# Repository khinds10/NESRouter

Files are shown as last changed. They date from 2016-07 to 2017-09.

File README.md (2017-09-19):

# NESRouter
## Using an Old Nintendo Entertainment system case, produce a highly functional home router using a RaspberryPI 3

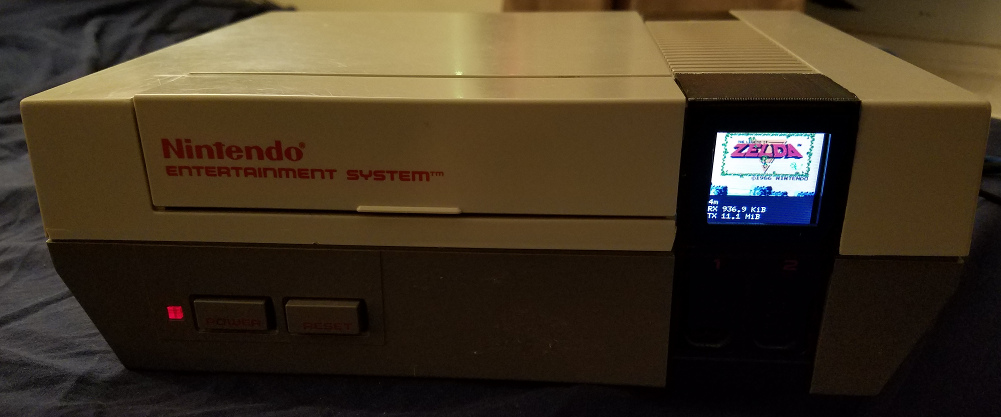
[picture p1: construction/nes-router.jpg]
NES Router w/Screen


#### 1) Flashing RaspberriPi Hard Disk / Install Required Software (Using Ubuntu Linux)

Download "RASPBIAN JESSIE LITE"
https://www.raspberrypi.org/downloads/raspbian/

**Create your new hard disk for DashboardPI**
>Insert the microSD to your computer via USB adapter and create the disk image using the `dd` command
>
> Locate your inserted microSD card via the `df -h` command, unmount it and create the disk image with the disk copy `dd` command
> 
> $ `df -h`
> */dev/sdb1       7.4G   32K  7.4G   1% /media/XXX/1234-5678*
> 
> $ `umount /dev/sdb1`
> 
> **Caution: be sure the command is completely accurate, you can damage other disks with this command**
> 
> *if=location of RASPBIAN JESSIE LITE image file*
> *of=location of your microSD card*
> 
> $ `sudo dd bs=4M if=/path/to/raspbian-jessie-lite.img of=/dev/sdb`
> *(note: in this case, it's /dev/sdb, /dev/sdb1 was an existing factory partition on the microSD)*

**Setting up your RaspberriPi**

*Insert your new microSD card to the raspberrypi and power it on with a monitor connected to the HDMI port*

Login
> user: **pi**
> pass: **raspberry**

Change your account password for security
>`sudo passwd pi`

Enable RaspberriPi Advanced Options
>`sudo raspi-config`

Choose:
`1 Expand File System`

`9 Advanced Options`
>`A2 Hostname`
>*change it to "NESRouter"*
>
>`A4 SSH`
>*Enable SSH Server*
>
>`A7 I2C`
>*Enable i2c interface*

**Enable the English/US Keyboard**

>`sudo nano /etc/default/keyboard`

> Change the following line:
>`XKBLAYOUT="us"`

**Setup the simple directory `l` command [optional]**

>`vi ~/.bashrc`
>
>*add the following line:*
>
>`alias l='ls -lh'`
>
>`source ~/.bashrc`

**Fix VIM default syntax highlighting [optional]**

>`sudo vi  /etc/vim/vimrc`
>
>uncomment the following line:
>
>_syntax on_

Reboot your PI to get the latest changes

`reboot`

### 2) Supplies needed

Old Nintendo Case from a broken NES (remove all the old contents inside the case, leaving only the outside frame, the power / reset buttons and the controller connections)

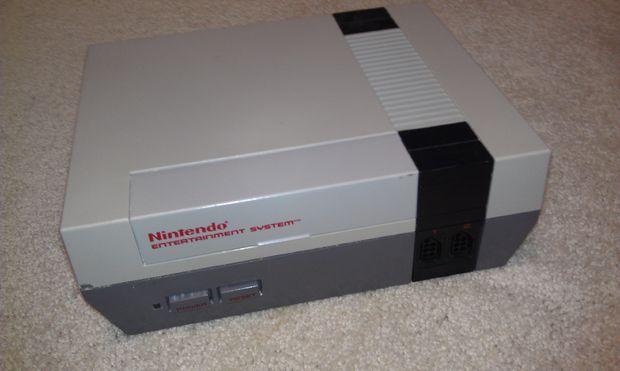
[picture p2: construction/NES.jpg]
Nintendo Case


Raspberry Pi 3 Model B

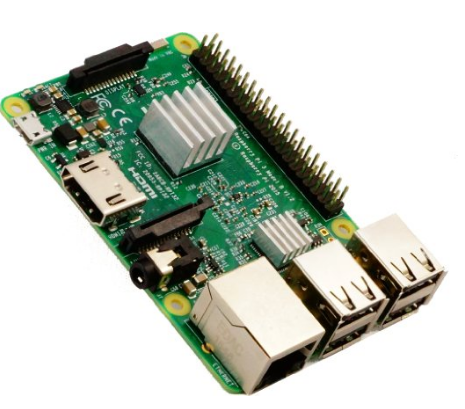
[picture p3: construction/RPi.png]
Raspberry PI 3


1.44" Serial:UART/I2C/SPI TFT LCD 128x128 Display Module

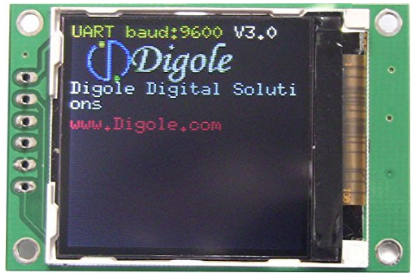
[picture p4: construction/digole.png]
Digole 1.44in display


5V 0.1A Mini Fan Raspberry Pi

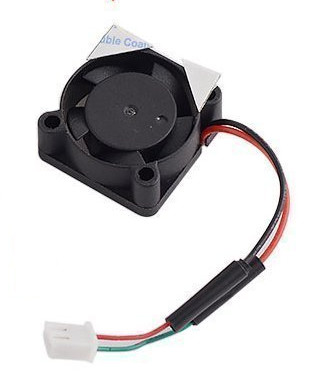
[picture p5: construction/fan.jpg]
Mini Fan


Ugreen USB 2.0 to 10/100 Fast Ethernet Lan Wired Network Adapter

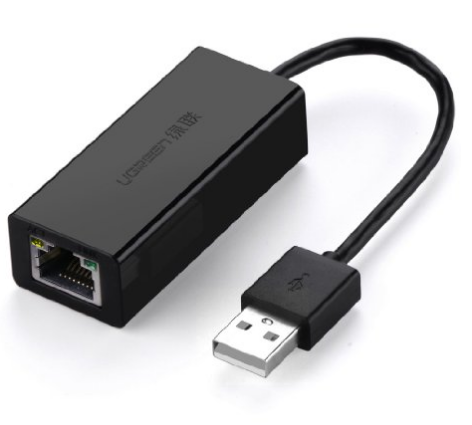
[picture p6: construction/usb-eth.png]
Ethernet USB


**Update local timezone settings**

`sudo dpkg-reconfigure tzdata`

`select your timezone using the interface`

### 3) Creating the WiFi Access Point
**Please note, before this becomes a router we're plugging in the RaspberryPi to an existing network via its ethernet port to install the following packages**

`sudo apt-get update && sudo apt-get -y upgrade`

`sudo apt-get install dnsmasq hostapd vim`

`sudo apt-get install vim git python-smbus i2c-tools python-imaging python-smbus build-essential python-dev rpi.gpio python3 python3-pip libi2c-dev`

`sudo vi /etc/dhcpcd.conf`

Add the following line:

    denyinterfaces wlan0

`sudo vi /etc/network/interfaces`

Edit the wlan0 section so that it looks like this:

    auto lo
    iface lo inet loopback

    iface eth0 inet manual

    auto wlan0
    iface wlan0 inet static
        address 10.0.10.1
        netmask 255.255.255.0
        network 10.0.10.0
        broadcast 10.0.10.255

    auto eth1
    iface eth1 inet static
        address 10.0.20.1
        netmask 255.255.255.0
        network 10.0.20.0
        broadcast 10.0.20.255

Reload DHCP Server and bounce the configuration for eth0 and wlan0 connections

`sudo service dhcpcd restart`

`sudo ifdown eth0; sudo ifup wlan0`

#### Configure HOSTAPD (Change ssid and wpa_passphrase to the values of your own choosing)

`sudo vi /etc/hostapd/hostapd.conf`

    # This is the name of the WiFi interface we configured above
    interface=wlan0

    # Use the nl80211 driver with the brcmfmac driver
    driver=nl80211

    # This is the name of the network
    ssid=NintendoWiFi

    # Use the 2.4GHz band
    hw_mode=g

    # Use channel 6
    channel=6

    # Enable 802.11n
    ieee80211n=1

    # Enable WMM
    wmm_enabled=1

    # Enable 40MHz channels with 20ns guard interval
    ht_capab=[HT40][SHORT-GI-20][DSSS_CCK-40]

    # Accept all MAC addresses
    macaddr_acl=0

    # Use WPA authentication
    auth_algs=1

    # Require clients to know the network name
    ignore_broadcast_ssid=0

    # Use WPA2
    wpa=2

    # Use a pre-shared key
    wpa_key_mgmt=WPA-PSK

    # The network passphrase
    wpa_passphrase=password

    # Use AES, instead of TKIP
    rsn_pairwise=CCMP

We can check if it's working at this stage by running (but doesn't have full internet connectivity yet):

`sudo /usr/sbin/hostapd /etc/hostapd/hostapd.conf`

`sudo vi /etc/default/hostapd`

Find the line 

    #DAEMON_CONF="" 
    
and replace it with 

    DAEMON_CONF="/etc/hostapd/hostapd.conf"

Configure DNSMASQ

`sudo mv /etc/dnsmasq.conf /etc/dnsmasq.conf.orig`

`sudo vi /etc/dnsmasq.conf`

    bind-interfaces           # Bind to the interface to make sure we aren't sending things elsewhere
    server=8.8.8.8            # Forward DNS requests to Google DNS
    domain-needed             # Don't forward short names
    bogus-priv                # Never forward addresses in the non-routed address spaces.

    # Assign IP addresses w/infinite lease time (for device usage stats)
    dhcp-range=wlan0,10.0.10.100,10.0.10.200,255.255.255.0,10.0.10.255,infinite
    dhcp-range=eth1,10.0.20.100,10.0.20.200,255.255.255.0,10.0.20.255,infinite 

SET UP IPV4 FORWARDING

`sudo vi /etc/sysctl.conf`

[uncomment]
net.ipv4.ip_forward=1

Activate it immediately with
`sudo sh -c "echo 1 > /proc/sys/net/ipv4/ip_forward"`

`sudo iptables -t nat -A POSTROUTING -o eth0 -j MASQUERADE`

`sudo iptables -A FORWARD -i eth0 -o eth1 -m state --state RELATED,ESTABLISHED -j ACCEPT`

`sudo iptables -A FORWARD -i eth1 -o eth0 -j ACCEPT`

`sudo iptables -A FORWARD -i eth0 -o wlan0 -m state --state RELATED,ESTABLISHED -j ACCEPT`

`sudo iptables -A FORWARD -i wlan0 -o eth0 -j ACCEPT`

Save iptables settings for next reboot

`sudo sh -c "iptables-save > /etc/iptables.ipv4.nat"`

Create ipv4 rules file (with new contents)

`sudo vi /lib/dhcpcd/dhcpcd-hooks/70-ipv4-nat`

    iptables-restore < /etc/iptables.ipv4.nat

Restart Services

`sudo service hostapd start`
`sudo service dnsmasq start`

`sudo reboot`

#### Assigning Static IPs [Optional]
**If you would like hosts on your network to have static ips please use the following**

Aquire the hosts currently connected via DHCP
`vi /var/lib/misc/dnsmasq.leases`

Add the MAC Address (from output above) and the IP address you would like to assign them to
`sudo vi /etc/dnsmasq.conf`

    # main desktop
    dhcp-host=12:34:56:78:9a:bc,10.0.20.20

**Note: This will assign the network interface with the MAC Address: 12:34:56:78:9a:bc to IP address 10.0.20.20. The IP address listed does NOT have to be in the DHCP range given, just on the same subnet.  My main desktop above is on subnet eth1:10.0.20.0, so I gave it IP Address of 10.0.20.20.**

#### Adding UFW Firewall

`sudo apt-get install ufw`

Allow port 22 for public use (for remote network access)

`sudo ufw allow 22`

Allow all ports on my local network

`sudo ufw allow from 10.0.10.0/24`
`sudo ufw allow from 10.0.20.0/24`

Allow web ports to everyone

`sudo ufw allow 80`

Allow secure web ports to everyone

`sudo ufw allow 443`

Enable UFW and check the status

`sudo ufw --force enable`

`sudo ufw status`

Fix BUG with UFW not starting on startup

`sudo su`
`crontab -e`

Add the following line:
`@reboot /bin/sleep 60; ufw --force enable`

## Construction

### Install inside the NES

1) Using a 3D printer print the Digole Display frame "NESPanel" in the `/construction/display-frame/` folder. [if you don't have a 3D printer you could delicately cut a square hole for the Digole Display with a Dremel tool]

2) Cut the following holes open in the back and side of the case to allow for the small fan to be fastened on the side and the
power/ethernet and USB ethernet cables to get in through the back.

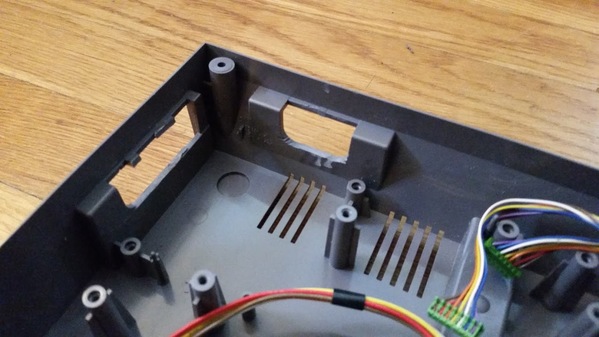
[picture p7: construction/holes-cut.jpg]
Holes Cut


3) Unscrew the top right black panel from the NES and cleanly cut a large enough square hole to mount your digole display. Hot Glue the display in place with the "NESPanel" 3D printed frame over the top of it.

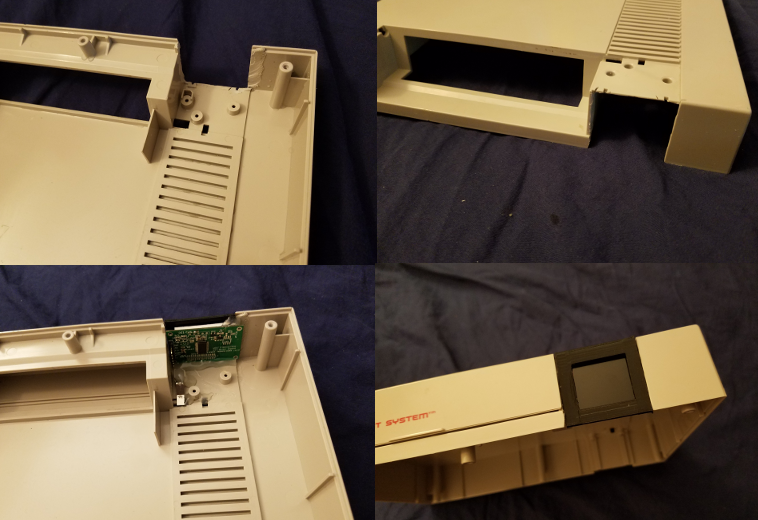
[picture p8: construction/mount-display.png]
Mount Digole Display


4) Mount the RaspberryPi in the middle of the bottom of the empty NES case, fasten by glue or a small screw through the bottom.
Using a 270 ohm resister, connect the "power on LED" of the NES to the 5V and GND pins in the Raspberry Pi (short LED lead is the ground).
Connect the small fan to the 5V and GND pins as well to have it run when the unit starts up, glue the fan against the hole in the side for it.

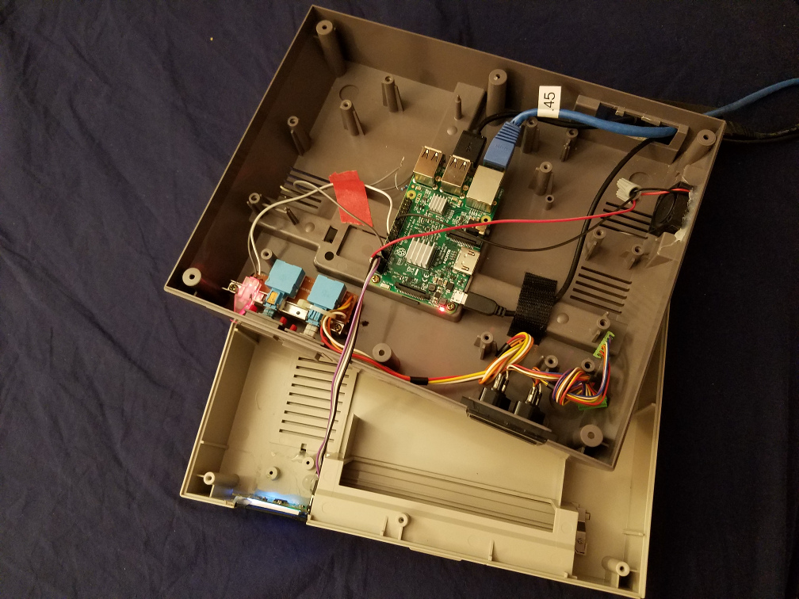
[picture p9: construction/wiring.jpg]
Wiring

 
### Connecting the Digole Display

Connect the following pins to the pins on the RaspberryPi
    
    VCC is connected to 3v
    GND is ground
    DATA is SDA
    CLOCK is SCL

Now you should see the device in your i2cdetect command

`i2cdetect -y 1`
*it should show up in the grid of text as 27*

### Install network monitoring tools & DB Logging

`sudo apt-get install ifstat memcached python-memcache postgresql postgresql-contrib python-psycopg2`

`sudo vi /etc/postgresql/9.4/main/pg_hba.conf`
>Add the following line to the end of the file:
>local all pi password

`sudo -i -u postgres`

`psql`

`create role pi password 'password here';`

`alter role pi login;`

`alter role pi superuser;`

`\du`

>(you should see your PI user with the permissions granted)

`create database network_stats;`

`\q`

`exit`

`psql -d network_stats`

Run the following queries:
        
>CREATE TABLE traffic\_per\_minute (
>    id serial,
>    time timestamp without time zone NOT NULL,
>    eth0\_down real,
>    eth0\_up real,
>    eth1\_down real,
>    eth1\_up real,
>    wan0\_down real,
>    wan0\_up real
>);
> 
>CREATE UNIQUE INDEX time\_idx ON traffic\_per\_minute (time);

Copy the "logging" folder of code from this project to the home directory of your RPi

`crontab -e`

Add this line

`@reboot /bin/sleep 60; nohup python /home/pi/logging/networkUsage.py >/dev/null 2>&1`

### Install the traffic summary report (runs every 5 minutes by cronjob)

`crontab -e`

add the following line

> */5 * * * * python /home/pi/logging/trafficSummary.py

### Install the dashboard screen

Copy the "display" folder of code from this project to the home directory of your RPi

Run it as follows

>$ `python /home/pi/display/NESRouter.py`

Setup the display script to run at startup

`crontab -e`

Add this line

`@reboot nohup python /home/pi/display/NESRouter.py >/dev/null 2>&1`

Verify the display starts working on reboot

`sudo reboot`

### Install the local usage/statistics website [http://10.0.10.1]

`sudo apt-get update && sudo apt-get upgrade -y`

`sudo apt-get install apache2`

`sudo service apache2 restart`

Remove default pages

`cd /var/www`

`sudo rm -rf html`
   
Copy 'webportal' folder from this project to your home folder on your RPi and create the symlink for apache to use
  
`cd /var/www`

`sudo ln -s /home/pi/webportal html`

`cd /var/www/html`

`chmod +x *.py`

`sudo a2enmod cgi`

`sudo vi /etc/apache2/sites-enabled/000-default.conf`

Enable Python CGI Scripting 

**Add inside the <virtual\> tag**

> <Directory /var/www/html\>
>   Options +ExecCGI
>   AddHandler cgi-script .py
> </Directory\>

`sudo service apache2 restart`
 
You can now visit the local HTTP site [http://10.0.10.1]

### Setup advanced network monitoring (via IPFM)

`sudo apt-get update`

`sudo apt-get install ipfm`

`sudo mv /etc/ipfm.conf /etc/ipfm.conf-bak`

`sudo vi /etc/ipfm.conf`

Create with the following contents:

> \# Global variables
> 
> \# IPFM can monitor only one device.
> DEVICE eth0
> 
> \# GLOBAL LOGGING CONFIGURATION
> LOG
> 
> FILENAME "/var/log/ipfm/%Y_%d_%m/%H_%M"
> 
> \# log every minute
> DUMP EVERY 1 minute
> 
> \# clear statistics each day
> CLEAR EVERY 24 hour
> SORT IN
> RESOLVE

`sudo service ipfm start`

## OPTIONAL: Creating your own Nintendo images to render on the display

Upload your own 128x128 file to the following URL:

http://www.digole.com/tools/PicturetoC_Hex_converter.php 

Choose your image file to upload, add what size you want it to be on the screen (Width/Height)

Select "256 Color for Color OLED/LCD(1 byte/pixel)" in the "Used for" dropdown

Obtain the hex output.

Add the hex output to a display/build/ header (.h) file, use the other ones as guides for syntax.

Include the new file in the digole.c file 
`#include "myimage.h`

Include a new command line hook to your image file in the.
_Note: the command below is saying draw your image at position 10 pixels over 10  pixels down. You can change it to different X,Y coordinates, you can also change the values 128,128 to whatever size your new image actually is._

`} else if (strcmp(digoleCommand, "myimage") == 0) {`
    `drawBitmap256(10, 10, 128, 128, &myimageVariableHere,0);  // myimageVariableHere is defined in your (.h) file`
`}`

Now rebuild (ignore the errors) below to have your new image render with the following command.
>$ `./digole myimage`

**Re-Building [Included] Digole Display Driver for your optional changes**

>$ `cd display/build`

>$ `gcc digole.c`

>$ `mv a.out ../../digole`

>$ `chmod +x ../../digole`

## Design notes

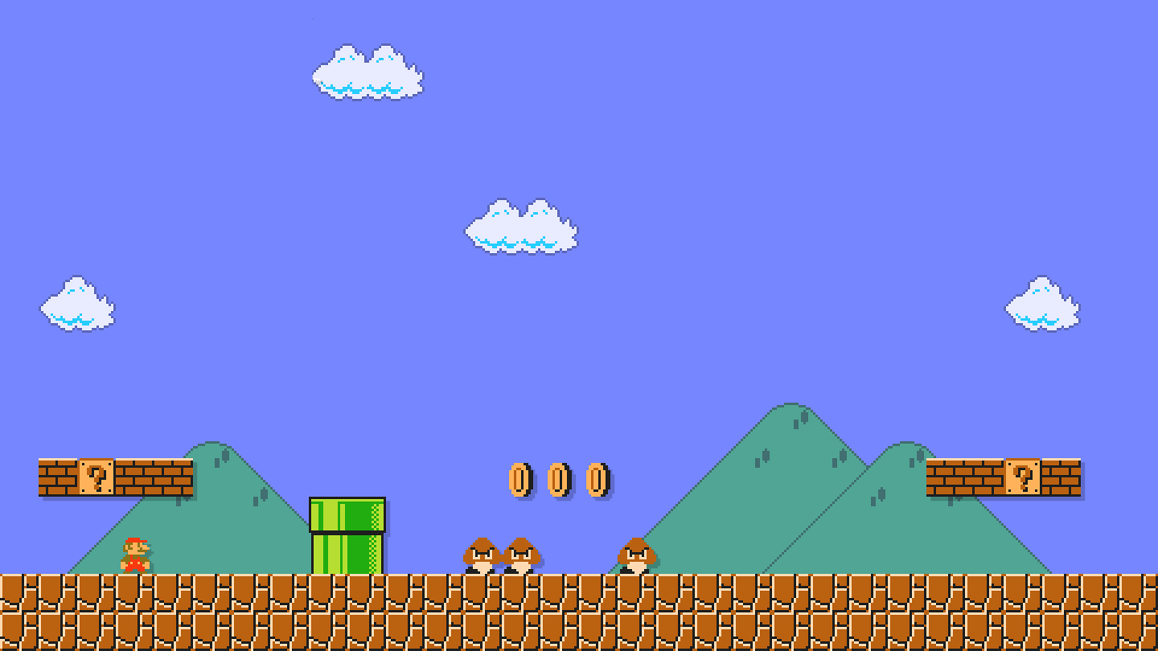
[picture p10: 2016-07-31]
webportal/img/wallpaper.png

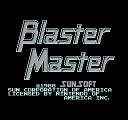
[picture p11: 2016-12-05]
display/compile/images/BlasterMaster.png

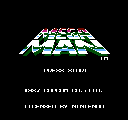
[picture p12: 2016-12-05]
display/compile/images/MegaMan.png

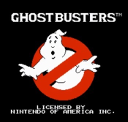
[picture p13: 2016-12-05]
display/compile/images/GhostBusters.png

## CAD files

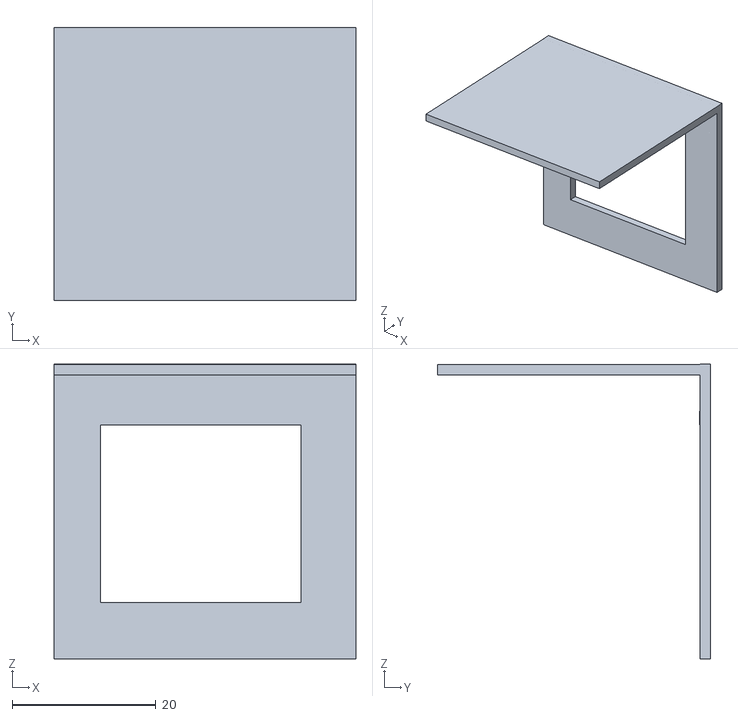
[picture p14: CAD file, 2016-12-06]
construction/display-frame/nesPanel.stl
42.0 x 38.0 x 41.0

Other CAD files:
construction/display-frame/nesPanel.blend

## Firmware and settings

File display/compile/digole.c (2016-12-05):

/////////////////////////////////
// Digole Digital
/////////////////////////////////
#include <arpa/inet.h>
#include <dirent.h>
#include <errno.h>
#include <net/if.h>
#include <netinet/in.h>
#include <netinet/in.h>
#include <pthread.h>
#include <stdint.h>
#include <stdio.h>
#include <stdlib.h>
#include <string.h>
#include <stropts.h>
#include <sys/ioctl.h>
#include <sys/socket.h>
#include <sys/types.h>
#include <sys/time.h>
#include <time.h>
#include <unistd.h>
#include <inttypes.h>
#include <linux/i2c-dev.h>
#include <fcntl.h>
#include <sys/ioctl.h>
#include <sys/stat.h>

// include all the NES Title Screen Images
#include "BlasterMaster.h""
#include "Castlevania.h""
#include "ChipDale.h""
#include "Contra.h""
#include "DuckTales.h""
#include "Galaga.h""
#include "GhostBusters.h""
#include "Gradius.h""
#include "KidIcarus.h""
#include "MarbleMadness.h""
#include "MegaMan.h""
#include "MetalGear.h""
#include "Metroid.h""
#include "PunchOut.h""
#include "SuperMario2.h""
#include "SuperMario3.h""
#include "TMNT2.h""
#include "TopGun.h""
#include "Turtles.h""
#include "Zelda.h""

#define _TEXT_ 0
#define _GRAPH_ 1
#define _rs 0
#define _rst 2
#define LCDWIDTH 128
#define LCDHEIGHT 64

// an abs() :)
#define abs(a) (((a) < 0) ? -(a) : (a))

// bit set
#define _BV(bit) (0x1 << (bit))
#define swap(a, b) { uint8_t t = a; a = b; b = t; }

int fd,fd2;
const unsigned char fonts[] = {6, 10, 18, 51, 120, 123};

// name of the port we will be using, Rasberry Pi model B (i2c-1)
char *fileName = "/dev/i2c-1";

// address of I2C device Digole
int  address = 0x27;

void delay (unsigned int howLong){
  struct timespec sleeper, dummy ;
  sleeper.tv_sec  = (time_t)(howLong / 1000) ;
  sleeper.tv_nsec = (long)(howLong % 1000) * 1000000 ;
  nanosleep (&sleeper, &dummy) ;
}
 int writebyte (uint8_t command) {
	    if( i2c_smbus_write_byte( fd, command ) < 0 ) {
            printf(" Error writing to i2c slave ");
			return -1;
        }
		return 0;
 }
 int writecmd(char *command) {
		char tmp[1000];
		int i;
		sprintf(tmp,"%s",command);
        printf(" Digole CMD: %s ",command);
		for (i=0;i<strlen(tmp);i++) {
			printf("%c",tmp[i]);
		    if ((writebyte(tmp[i]))==-1) {
				printf(" Error writing to i2c slave ");
				return -1;
			}
		}
		return 0;
 }
void setRot90(void) {
    writecmd("SD1");
}
void setRot180(void) {
    writecmd("SD2");
}
void setRot270(void) {
    writecmd("SD3");
}
void undoRotation(void) {
    writecmd("SD0");
}
void setRotation(uint8_t d) {
    writecmd("SD");
    writebyte(d);
}
void setContrast(uint8_t c) {
    writecmd("CT");
    writebyte(c);
}
int print(char *command) {
    char tmp[1000];
    writecmd("TT");
    writecmd(command);
    writebyte(0);
    return 0;
}
void displayStartScreen(uint8_t c) {
    writecmd("DSS");
    writebyte(c);
}
void drawBox(uint8_t x, uint8_t y, uint8_t w, uint8_t h) {
    writecmd("FR");
    writebyte(x);
    writebyte(y);
    writebyte(x + w);
    writebyte(y + h);
}
void drawFrame(uint8_t x, uint8_t y, uint8_t w, uint8_t h) {
    writecmd("DR");
    writebyte(x);
    writebyte(y);
    writebyte(x + w);
    writebyte(y + h);
}
void setColor(uint8_t color) {
    writecmd("SC");
    writebyte(color);
}
void drawBoxfill(uint8_t x, uint8_t y, uint8_t w, uint8_t h) {
	setColor(0);
	drawBox(x, y, w,h);
	setColor(1);
	drawFrame(x, y, w,h);
}
void clearobd() {
	setColor(0);
	drawBox(0, 0, 128,57);
	setColor(1);
}
void drawCircle(uint8_t x, uint8_t y, uint8_t r, uint8_t f) {
    writecmd("CC");
    writebyte(x);
    writebyte(y);
    writebyte(r);
    writebyte(f);
}
void drawDisc(uint8_t x, uint8_t y, uint8_t r) {
    drawCircle(x, y, r, 1);
}
void drawPixel(uint8_t x, uint8_t y, uint8_t color) {
    writecmd("DP");
    writebyte(x);
    writebyte(y);
    writebyte(color);
}
void drawLine(uint8_t x, uint8_t y, uint8_t x1, uint8_t y1) {
    writecmd("LN");
    writebyte(x);
    writebyte(y);
    writebyte(x1);
    writebyte(y1);
}
void drawLineTo(uint8_t x, uint8_t y) {
    writecmd("LT");
    writebyte(x);
    writebyte(y);
}
void drawHLine(uint8_t x, uint8_t y, uint8_t w) {
    drawLine(x, y, x + w, y);
}
void drawVLine(uint8_t x, uint8_t y, uint8_t h) {
    drawLine(x, y, x, y + h);
}
void nextTextLine(void) {
    writebyte((uint8_t) 0);
    writecmd("TRT");
}
void setFont(uint8_t font) {
    writecmd("SF");
    writebyte(font);
}
void directCommand(uint8_t d) {
    writecmd("MCD");
    writebyte(d);
}
void directData(uint8_t d) {
    writecmd("MDT");
    writebyte(d);
}
void moveArea(uint8_t x0, uint8_t y0, uint8_t x1, uint8_t y1, char xoffset, char yoffset) {
    writecmd("MA");
    writebyte(x0);
    writebyte(y0);
    writebyte(x1);
    writebyte(y1);
    writebyte(xoffset);
    writebyte(yoffset);
}
void uploadStartScreen(int lon,  uint8_t *data,int xdelay) {
     int j,y;
     uint8_t c;
    writecmd("SSS");
    writebyte((uint8_t) (lon % 256));
    writebyte((uint8_t) (lon / 256));
    for (j = 0; j < lon;j++) {
        delay(xdelay);
        c=*(data+j);
        writebyte(c);
		printf(" 0x%.2X ",c);
		if ((j%16)==0) printf(" ");
    }
}
void uploadUserFont(int lon, uint8_t *data, uint8_t sect) {
     uint8_t c;
	 int j;
    writecmd("SUF");
    writebyte(sect);
    writebyte((uint8_t) (lon % 256));
    writebyte((uint8_t) (lon / 256));
    for ( j = 0; j < lon; j++) {
        if((j%32)==0) delay(10);
        delay(2);
        c=*(data+j);
        writebyte(c);
    }
}
void clearScreen(void) {
        writebyte('C');
		writebyte('L');
		writebyte(0);
		writebyte('C');
		writebyte('L');
		writebyte(0);
}
//set display mode
void setMode(uint8_t m) {
        writecmd("DM");
        writebyte(m);
}
//set text position back to previous, only one back allowed
void setTextPosBack(void) {
	writecmd("ETB");
}
void setTextPosOffset(char xoffset, char yoffset) {
	writecmd("ETO");
	writebyte(xoffset);
	writebyte(yoffset);
}
void setTextPosAbs(uint8_t x, uint8_t y) {
	writecmd("ETP");
	writebyte(x);
	writebyte(y);
}
void setLinePattern(uint8_t pattern) {
	writecmd("SLP");
	writebyte(pattern);
 }
void setPrintPos(uint8_t x, uint8_t y, uint8_t graph ) {
        if (graph == _TEXT_)
            writecmd("TP");
		else
            writecmd("GP");
         writebyte(x);
         writebyte(y);
}
void disableCursor(void) {
    writecmd("CS0");
}
void enableCursor(void) {
    writecmd("CS1");
}
void drawStr(uint8_t x, uint8_t y, char *s) {
		setTextPosOffset(x,y);
		print(s);
}
/*----------Functions for Graphic LCD/OLED adapters only---------*/
void drawBitmap(uint8_t x, uint8_t y, uint8_t w, uint8_t h, const uint8_t *bitmap) {
    uint8_t i = 0;
	int j;
    if ((w & 7) != 0)
        i = 1;
    writecmd("DIM");
    writebyte(x); //x;
    writebyte(y);
    writebyte(w);
    writebyte(h);
    for ( j = 0; j < h * ((w >> 3) + i); j++) {
        writebyte(*(bitmap + j));
    }
}
void drawBitmap256(uint8_t x, uint8_t y, uint8_t w, uint8_t h, unsigned char *bitmap,uint8_t c ) {
	int j;
    writecmd("EDIM1");
    writebyte(x);
    writebyte(y);
    writebyte(w);
    writebyte(h);    
    for ( j = 0; j < h * w; j++) {
        writebyte(*(bitmap + j));
    }
}
void drawBitmapc(uint8_t x, uint8_t y, uint8_t w, uint8_t h, unsigned char *bitmap,uint8_t c ) {
    uint8_t i = 0;
	int j;
	if (c!=0) c=0xff;
    if ((w & 7) != 0)
        i = 1;
    writecmd("EDIM1");
    writebyte(x);
    writebyte(y);
    writebyte(w);
    writebyte(h);
    for ( j = 0; j < h * ((w >> 3) + i); j++) {
        writebyte((*(bitmap + j))^c);
    }
}
const char *byte_to_binary(int x) {
    static char b[9];
    b[0] = '\0';
    int z;
    for (z = 128; z > 0; z >>= 1){
        strcat(b, ((x & z) == z) ? "1" : "0");
    }
    return b;
}
 int printxy(uint8_t x, uint8_t y, char *command) {
	setPrintPos(x, y,_TEXT_);
	writecmd("TT");
	writecmd(command);
	writebyte(0);
	return 0;
 }
 int printxy_abs(uint8_t x, uint8_t y, char *command) {
	setTextPosAbs(x, y);
	writecmd("TT");
	writecmd(command);
	writebyte(0);
	return 0;
 }
 int printxyf_abs(uint8_t x, uint8_t y,uint8_t font, char *command) {
	setFont(fonts[font]);
	setTextPosAbs(x, y);
	writecmd("TT");
	writecmd(command);
	writebyte(0);
	return 0;
 }
int printxyf(uint8_t x, uint8_t y,uint8_t font, char *command) {
	setFont(fonts[font]);
	setPrintPos(x, y,_TEXT_);
	writecmd("TT");
	writecmd(command);
	writebyte(0);
	return 0;
 }
int printnxyf(uint8_t x, uint8_t y,uint8_t font, int command) {
    char tmp[100];
    sprintf(tmp,"%d",command);
    setFont(fonts[font]);
    setPrintPos(x, y,_TEXT_);
    writecmd("TT");
    writecmd(tmp);
    writebyte(0);
    return 0;
 }
 int printnxyf_abs(uint8_t x, uint8_t y,uint8_t font, int command) {
    char tmp[100];
    sprintf(tmp,"%d",command);
    setFont(fonts[font]);
    setTextPosAbs(x, y);
    writecmd("TT");
    writecmd(tmp);
    writebyte(0);
    return 0;
 }
int LCDInit( uint8_t contrast) {
    // Open port for reading and writing
    if ((fd = open (fileName, O_RDWR)) < 0) {
        printf(" Failed to open i2c port ");
        return -1;
    }
    // Set the port options and set the address of the device
    if (ioctl(fd, I2C_SLAVE, address) < 0) {
        printf(" Unable to get bus access to talk to slave ");
        return -1;
    }
	return (0);
}
void LCDdrawbitmap(uint8_t x, uint8_t y, uint8_t *bitmap, uint8_t w, uint8_t h,uint8_t color,uint8_t *dest) {
uint8_t j,i,jj;
uint8_t o,p,k;
printf(" 000 0b ");
k=0;
for (p=0;p<(w/8);p++)
  for (o=0;o<=7;o++) {
		for ( j=0; j<h; j++) {
			for ( i=0; i<(w/8); i++ ) {
				uint8_t d = *(bitmap + i + (j)*w/8);
				for (jj = 8; jj>0; jj--)	{
					if (((jj-1)==(7-o)) && (i==p)) {
						if (d & _BV(jj-1))
						  printf("1");
						else
						  printf("0");
						k++;
						if (k%8==0)
							printf(",0b");
					 }
				}
			}
		}
		k=0;
		printf(" %.03d 0b ",(p*8)+o);
	}
}

int main (int argc, char* argv[]) {
    int i=0;
	LCDInit(0);
    printf(" %s ", argv[0]);

    // show incoming commands   
    printf(" arg%d=%s ", 1, argv[1]);
    printf(" arg%d=%s ", 2, argv[2]);

    // parse command to char
    char digoleCommand[100];
    sprintf(digoleCommand,"%s",argv[1]);
    
    // based on command issue call to Digole screen
    if (strcmp(digoleCommand, "setRot90") == 0) {
        setRot90();
    } else if (strcmp(digoleCommand, "setRot180") == 0) {
        setRot180();
    } else if (strcmp(digoleCommand, "setRot270") == 0) {
        setRot270();
    } else if (strcmp(digoleCommand, "undoRotation") == 0) {
        undoRotation();
    } else if (strcmp(digoleCommand, "setRotation") == 0) {
        setRotation((uint8_t)atoi(argv[2]));
    } else if (strcmp(digoleCommand, "setContrast") == 0) {
        setContrast((uint8_t)atoi(argv[2]));
    } else if (strcmp(digoleCommand, "displayStartScreen") == 0) {
        displayStartScreen((uint8_t)atoi(argv[2]));
    } else if (strcmp(digoleCommand, "drawBox") == 0) {
        drawBox((uint8_t)atoi(argv[2]), (uint8_t)atoi(argv[3]), (uint8_t)atoi(argv[4]), (uint8_t)atoi(argv[5]));
    } else if (strcmp(digoleCommand, "drawFrame") == 0) {
        drawFrame((uint8_t)atoi(argv[2]), (uint8_t)atoi(argv[3]), (uint8_t)atoi(argv[4]), (uint8_t)atoi(argv[5]));
    } else if (strcmp(digoleCommand, "setColor") == 0) {
        setColor((uint8_t)atoi(argv[2]));
    } else if (strcmp(digoleCommand, "drawBoxfill") == 0) {
        drawBoxfill((uint8_t)atoi(argv[2]), (uint8_t)atoi(argv[3]), (uint8_t)atoi(argv[4]), (uint8_t)atoi(argv[5]));
    } else if (strcmp(digoleCommand, "clearobd") == 0) {
        clearobd();
    } else if (strcmp(digoleCommand, "drawCircle") == 0) {
        drawCircle((uint8_t)atoi(argv[2]), (uint8_t)atoi(argv[3]), (uint8_t)atoi(argv[4]), (uint8_t)atoi(argv[5]));
    } else if (strcmp(digoleCommand, "drawDisc") == 0) {
        drawDisc((uint8_t)atoi(argv[2]), (uint8_t)atoi(argv[3]), (uint8_t)atoi(argv[4]));
    } else if (strcmp(digoleCommand, "drawPixel") == 0) {
        drawPixel((uint8_t)atoi(argv[2]), (uint8_t)atoi(argv[3]), (uint8_t)atoi(argv[4]));
    } else if (strcmp(digoleCommand, "drawLine") == 0) {
        drawLine((uint8_t)atoi(argv[2]), (uint8_t)atoi(argv[3]), (uint8_t)atoi(argv[4]), (uint8_t)atoi(argv[5]));
    } else if (strcmp(digoleCommand, "drawLineTo") == 0) {
        drawLineTo((uint8_t)atoi(argv[2]), (uint8_t)atoi(argv[3]));
    } else if (strcmp(digoleCommand, "drawHLine") == 0) {
        drawHLine((uint8_t)atoi(argv[2]), (uint8_t)atoi(argv[3]), (uint8_t)atoi(argv[4]));
    } else if (strcmp(digoleCommand, "drawVLine") == 0) {
        drawVLine((uint8_t)atoi(argv[2]), (uint8_t)atoi(argv[3]), (uint8_t)atoi(argv[4]));
    } else if (strcmp(digoleCommand, "nextTextLine") == 0) {
        nextTextLine();
    } else if (strcmp(digoleCommand, "setFont") == 0) {
        setFont((uint8_t)atoi(argv[2]));
    } else if (strcmp(digoleCommand, "directCommand") == 0) {
        directCommand((uint8_t)atoi(argv[2]));
    } else if (strcmp(digoleCommand, "directData") == 0) {
        directData((uint8_t)atoi(argv[2]));
    } else if (strcmp(digoleCommand, "moveArea") == 0) {
        moveArea((uint8_t)atoi(argv[2]), (uint8_t)atoi(argv[3]), (uint8_t)atoi(argv[4]), (uint8_t)atoi(argv[5]), (uint8_t)atoi(argv[6]), (uint8_t)atoi(argv[7]));
    } else if (strcmp(digoleCommand, "uploadStartScreen") == 0) {
        // uploadStartScreen(int lon,  uint8_t *data,int xdelay);
    } else if (strcmp(digoleCommand, "uploadUserFont") == 0) {
        // uploadUserFont(int lon, uint8_t *data, uint8_t sect);
    } else if (strcmp(digoleCommand, "clear") == 0) {
        clearScreen();
    } else if (strcmp(digoleCommand, "setMode") == 0) {
        setMode((uint8_t)atoi(argv[2]));
    } else if (strcmp(digoleCommand, "setTextPosBack") == 0) {
        setTextPosBack();
    } else if (strcmp(digoleCommand, "setTextPosOffset") == 0) {
        setTextPosOffset((uint8_t)atoi(argv[2]), (uint8_t)atoi(argv[3]));
    } else if (strcmp(digoleCommand, "setTextPosAbs") == 0) {
        setTextPosAbs((uint8_t)atoi(argv[2]), (uint8_t)atoi(argv[3]));
    } else if (strcmp(digoleCommand, "setLinePattern") == 0) {
        setLinePattern((uint8_t)atoi(argv[2]));
    } else if (strcmp(digoleCommand, "setPrintPos") == 0) {
        setPrintPos((uint8_t)atoi(argv[2]), (uint8_t)atoi(argv[3]), (uint8_t)atoi(argv[4]));
    } else if (strcmp(digoleCommand, "disableCursor") == 0) {
        disableCursor();
    } else if (strcmp(digoleCommand, "enableCursor") == 0) {
        enableCursor();
    } else if (strcmp(digoleCommand, "drawStr") == 0) {
        drawStr((uint8_t)atoi(argv[2]), (uint8_t)atoi(argv[3]), argv[4]);
    } else if (strcmp(digoleCommand, "drawBitmap") == 0) {
        // drawBitmap((uint8_t)atoi(argv[2]), (uint8_t)atoi(argv[3]), (uint8_t)atoi(argv[4]), (uint8_t)atoi(argv[5]), (uint8_t)atoi(argv[2]));
    } else if (strcmp(digoleCommand, "drawBitmap256") == 0) {
        // drawBitmapc((uint8_t)atoi(argv[2]), (uint8_t)atoi(argv[2]), (uint8_t)atoi(argv[2]), (uint8_t)atoi(argv[2]), const uint8_t *bitmap,uint8_t c );
    } else if (strcmp(digoleCommand, "print") == 0) {
        print(argv[2]);
    } else if (strcmp(digoleCommand, "printxy") == 0) {
        printxy((uint8_t)atoi(argv[2]), (uint8_t)atoi(argv[3]), argv[4]);
    } else if (strcmp(digoleCommand, "printxy_abs") == 0) {
        printxy_abs((uint8_t)atoi(argv[2]), (uint8_t)atoi(argv[3]), argv[4]);
    } else if (strcmp(digoleCommand, "printxyf_abs") == 0) {
        printxyf_abs((uint8_t)atoi(argv[2]), (uint8_t)atoi(argv[3]),(uint8_t)atoi(argv[4]), argv[5]) ;
    } else if (strcmp(digoleCommand, "printxyf") == 0) {
        printxyf((uint8_t)atoi(argv[2]), (uint8_t)atoi(argv[3]),(uint8_t)atoi(argv[4]), argv[5]);
    } else if (strcmp(digoleCommand, "printnxyf") == 0) {
        printnxyf((uint8_t)atoi(argv[2]), (uint8_t)atoi(argv[3]),(uint8_t)atoi(argv[4]), (uint8_t)atoi(argv[5]));
    } else if (strcmp(digoleCommand, "printnxyf_abs") == 0) {
        printnxyf_abs((uint8_t)atoi(argv[2]), (uint8_t)atoi(argv[3]),(uint8_t)atoi(argv[4]), (uint8_t)atoi(argv[5]));
    } else if (strcmp(digoleCommand, "LCDdrawbitmap") == 0) {
        //LCDdrawbitmap((uint8_t)atoi(argv[2]), (uint8_t)atoi(argv[3]), (uint8_t)atoi(argv[4]), (uint8_t)atoi(argv[5]), (uint8_t)atoi(argv[6]),(uint8_t)atoi(argv[7]),(uint8_t)argv[8]);
    } else if (strcmp(digoleCommand, "BlasterMaster") == 0) {
        drawBitmap256(0, 0, 128, 120, &BlasterMaster,0);
    } else if (strcmp(digoleCommand, "Castlevania") == 0) {
        drawBitmap256(0, 0, 128, 112, &Castlevania,0);
    } else if (strcmp(digoleCommand, "ChipDale") == 0) {
        drawBitmap256(0, 0, 128, 120, &ChipDale,0);
    } else if (strcmp(digoleCommand, "Contra") == 0) {
        drawBitmap256(0, 0, 128, 120, &Contra,0);
    } else if (strcmp(digoleCommand, "DuckTales") == 0) {
        drawBitmap256(0, 0, 128, 112, &DuckTales,0);
    } else if (strcmp(digoleCommand, "Galaga") == 0) {
        drawBitmap256(0, 0, 128, 112, &Galaga,0);
    } else if (strcmp(digoleCommand, "GhostBusters") == 0) {
        drawBitmap256(0, 0, 128, 122, &GhostBusters,0);
    } else if (strcmp(digoleCommand, "Gradius") == 0) {
        drawBitmap256(0, 0, 128, 120, &Gradius,0);
    } else if (strcmp(digoleCommand, "KidIcarus") == 0) {
        drawBitmap256(0, 0, 128, 112, &KidIcarus,0);
    } else if (strcmp(digoleCommand, "MarbleMadness") == 0) {
        drawBitmap256(0, 0, 128, 120, &MarbleMadness,0);
    } else if (strcmp(digoleCommand, "MegaMan") == 0) {
        drawBitmap256(0, 0, 128, 120, &MegaMan,0);
    } else if (strcmp(digoleCommand, "MetalGear") == 0) {
        drawBitmap256(0, 0, 128, 120, &MetalGear,0);
    } else if (strcmp(digoleCommand, "Metroid") == 0) {
        drawBitmap256(0, 0, 128, 107, &Metroid,0);
    } else if (strcmp(digoleCommand, "PunchOut") == 0) {
        drawBitmap256(0, 0, 128, 112, &PunchOut,0);
    } else if (strcmp(digoleCommand, "SuperMario2") == 0) {
        drawBitmap256(0, 0, 128, 120, &SuperMario2,0);
    } else if (strcmp(digoleCommand, "SuperMario3") == 0) {
        drawBitmap256(0, 0, 128, 115, &SuperMario3,0);
    } else if (strcmp(digoleCommand, "TMNT2") == 0) {
        drawBitmap256(0, 0, 128, 112, &TMNT2,0);
    } else if (strcmp(digoleCommand, "TopGun") == 0) {
        drawBitmap256(0, 0, 128, 112, &TopGun,0);
    } else if (strcmp(digoleCommand, "Turtles") == 0) {
        drawBitmap256(0, 0, 128, 120, &Turtles,0);
    } else if (strcmp(digoleCommand, "Zelda") == 0) {
        drawBitmap256(0, 0, 128, 116, &Zelda,0);
    }
    printf("\n");
	return 0;
}

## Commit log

2016-06-29 add final notes about static ip address and switched to 10 block private IP address range
2016-12-02 add 3 printer panel, digole display with 20 NES images
    [nesPanel.blend, nesPanel.stl]
2016-12-05 revamp the NES images to show on the little screen
    [nesPanel.blend, nesPanel.stl]
2016-12-06 finalize the display driver in python
    [nesPanel.blend, nesPanel.stl]
2016-12-06 full path for the display driver needed
    [nesPanel.stl]
